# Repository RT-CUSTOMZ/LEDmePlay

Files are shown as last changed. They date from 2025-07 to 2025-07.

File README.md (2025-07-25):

# LEDmeplay-ESP32: Retro Arcade auf dem 32x32 RGB-Matrix-Display

Willkommen zum LEDmeplay-ESP32-Projekt!  

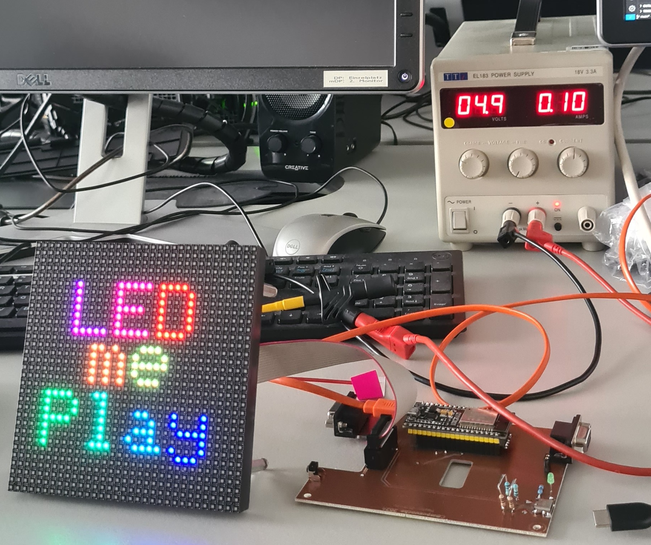
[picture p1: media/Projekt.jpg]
Bild von dem Projekt
 
Dieses Projekt bringt die klassischen LEDmeplay-Spiele von Mithotronic auf ein neues Level: Mit einem leistungsstarken ESP32 als Herzstück lassen sich mehrere Arcade-Spiele auf einem 32x32 Punkte großen RGB-LED-Matrix-Display ausführen und bequem über ein Startmenü auswählen.  
Ziel ist es, ein modulares Open-Source-System zu bieten, das an das Ursprungsprojekt **LEDmeplay für Arduino Mega 2560** anknüpft, aber durch die neue Hardware umfangreicher, moderner und vielseitiger wird.

## Übersicht

- **Plattform:** ESP32
- **Display:** 32x32 RGB-Matrix-LEDs
- **Projekttyp:** PlattformIO-Projekt (Arduino-Shell)
- **Basis:** Erweiterung des Originals von Mithotronic
- **Weitere Inhalte:** FreeCAD-Dateien (Gehäuse-Design als 3D-Druck), KiCad-Schaltpläne (Elektronik), SVG (Laser-Dateien für Gehäuse)

## Hauptfeatures & Verbesserungen

- **Mehrere Spiele:** Dank ESP32 können viele Spiele im Flash gespeichert und via Startmenü ausgewählt werden.
- **Zentrale Spiele-Bibliothek:** Gemeinsame Spiel-Logik und wiederkehrende Routinen wurden als Bibliothek gekapselt – optimale Basis für eigene Spiele-Entwicklungen und unkomplizierte Erweiterbarkeit.
- **Konstante Spielgeschwindigkeit:** Trotz höherer CPU-Geschwindigkeit laufen die klassischen Spiele weiterhin in Original-Geschwindigkeit.
- **Möglichkeit für aufwendigere Spiele:** Der ESP32 eröffnet neue Potenziale für anspruchsvollere Spiele.
- **Gut dokumentierte Beispieldateien:** CAD- und Layout-Daten unterstützen beim Nachbau.

## Bekannte Einschränkungen

- **IO-Pin-Engpass:** Die verfügbaren Pins des ESP32 sind durch Display, Steuerelemente u.a. Geräte fast vollständig belegt.
- **Gestiegene Komplexität:** Das Management mehrerer Spiele sowie die Menüstrukturen erhöhen die Komplexität des Codes. Dies kann das ursprüngliche Ziel, Einsteigerinnen und Einsteigern das Programmieren beizubringen, erschweren.

## Projektstruktur

Das Repository ist logisch gegliedert – jedes Unterverzeichnis enthält klar umrissene Inhalte für die einzelnen Projektaspekte:

| Verzeichnis | Inhalt |
|---|---|
| `/src` | Hauptquellcode für das ESP32-Board, inkl. Spiele, Menü, Bibliotheken |
| `/lib` | Wiederverwendbare Bibliotheken für Spiel-Logik, Displaysteuerung usw. |
| `/data` | Ressourcen wie Fonts, Sprites und Leveldaten |
| `/hardware/` | FreeCAD-Dateien für alle Gehäuseteile (STL für 3D-Druck lassen sich daraus erzeugen) sowie SVG-Dateien, um Gehäuseteile (Frontplatte, Halterungen) mit dem Lasercutter zu fertigen  |
| `/hardware/KiCad/` | KiCad-Projektdateien, Schaltpläne und Boardlayouts für die Elektronik |
| `/docs` | Dokumentation, Tutorials, Installationsanleitungen |

## Installation & Quickstart

1. **Voraussetzungen**
    - ESP32-Board
    - Windows, Mac oder Linux mit [PlatformIO](https://platformio.org/) und Arduino-Core
    - Lötkolben und Basiselektronik-Kenntnisse für Aufbau

2. **Firmware flashen**
    - Repository klonen:
      ```bash
      git clone https://github.com/RT-CUSTOMZ/LEDmePlay.git
      ```
    - PlatformIO-Projekt in VSCode öffnen
    - Board- und Port-Einstellungen anpassen (siehe `platformio.ini`)
    - Kompilieren & Upload:
      ```bash
      pio run --target upload
      ```

3. **Spiele auswählen**
    - Das Startmenü erscheint automatisch nach dem Boot.
    - Spiele lassen sich über angeschlossene Taster auswählen und starten.

## Hardware & Gehäuse

- **3D-Druckteile:**  
  Im Verzeichnis `/hardware/freecad` findest du alle FreeCAD-Dateien (FCStd), mit denen du die Gehäuseteile (z.B. Frontplatten, Halterungen) direkt im 3D-Drucker als STL exportieren kannst.

- **Elektronik und Platinen:**  
  Die Schaltpläne und Board-Layouts sind im Verzeichnis `/hardware/kicad` als KiCad-Projekt (Schaltplandateien, PCB) abgelegt.

- **Laser-Dateien:**  
  Vorlagen für Lasercutter (z.B. Acryl-Front, Tasten-Bohrungen) befinden sich unter `/hardware/`.

## Eigene Spiele entwickeln

- Die gemeinsame Spielelogik steht als Bibliothek unter `/lib` zur Verfügung.
- Beispielprojekte im `/src`-Verzeichnis können dupliziert und angepasst werden.

## Hinweise & Credits

- Dieses Projekt basiert auf dem genialen Ansatz von [Mithotronic LEDmeplay](https://mithotronic.de/ledmeplay.php)
- Bitte respektiere Lizenzen und Quellen beim Weiterverbreiten und Forken.
- Feedback, Fehlerberichte und Spielbeiträge gerne als Pull Request!

**Viel Spaß mit LEDmeplay-ESP32!**

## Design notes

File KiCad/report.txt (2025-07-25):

Hinweis: Verarbeite Symbol "D1:LED_THT:LED_D5.0mm_IRGrey".
Hinweis: Verarbeite Symbol "U1:Espressif:ESP32-DevKitC".
Hinweis: Verarbeite Symbol "SW1:Button_Switch_THT:SW_Tactile_SPST_Angled_PTS645Vx31-2LFS".
Hinweis: Verarbeite Symbol "R3:Resistor_THT:R_Axial_DIN0207_L6.3mm_D2.5mm_P10.16mm_Horizontal".
Hinweis: Verarbeite Symbol "R1:Resistor_THT:R_Axial_DIN0207_L6.3mm_D2.5mm_P10.16mm_Horizontal".
Hinweis: Verarbeite Symbol "Q1:Package_TO_SOT_THT:TO-92L".
Hinweis: Verarbeite Symbol "J6:Connector_Phoenix_MSTB:PhoenixContact_MSTBA_2,5_4-G-5,08_1x04_P5.08mm_Horizontal".
Hinweis: Verarbeite Symbol "J4:Connector_Dsub:DSUB-9_Female_Horizontal_P2.77x2.84mm_EdgePinOffset4.94mm_Housed_MountingHolesOffset7.48mm".
Hinweis: Verarbeite Symbol "J3:Connector_Dsub:DSUB-9_Female_Horizontal_P2.77x2.84mm_EdgePinOffset4.94mm_Housed_MountingHolesOffset7.48mm".
Hinweis: Verarbeite Symbol "J2:Connector_IDC:IDC-Header_2x08_P2.54mm_Vertical".
Hinweis: Verarbeite Symbol "H4:MountingHole:MountingHole_3.5mm".
Hinweis: Verarbeite Symbol "BZ1:Buzzer_Beeper:MagneticBuzzer_PUI_AT-0927-TT-6-R".
Hinweis: Verarbeite Symbol "D2:Diode_THT:D_A-405_P12.70mm_Horizontal".
Hinweis: Verarbeite Symbol "FID1:Fiducial:Fiducial_1.5mm_Mask3mm".
Hinweis: Verarbeite Symbol "FID2:Fiducial:Fiducial_1.5mm_Mask3mm".
Hinweis: Verarbeite Symbol "FID3:Fiducial:Fiducial_1.5mm_Mask3mm".
Hinweis: Verarbeite Symbol "H1:MountingHole:MountingHole_3.5mm_Pad_TopBottom".
Hinweis: Verarbeite Symbol "H2:MountingHole:MountingHole_3.5mm".
Hinweis: Verarbeite Symbol "H3:MountingHole:MountingHole_3.5mm".
Hinweis: Verarbeite Symbol "J1:Connector_BarrelJack:BarrelJack_Wuerth_6941xx301002".
Wert J6 von Conn_01x04_Socket in +5V-Display geändert.
J6 Pin 2 von +5V nach GND wieder verbunden.
J6 Pin 3 von GND nach +5V wieder verbunden.
J6 Pin 1 von +5V nach GND wieder verbunden.
J6 Pin 4 von GND nach +5V wieder verbunden.
Warnung: Kein Netz für Komponente J4 Pad 0 gefunden (kein Pin 0 in Symbol).
Warnung: Kein Netz für Komponente J4 Pad 0 gefunden (kein Pin 0 in Symbol).
Warnung: Kein Netz für Komponente J3 Pad 0 gefunden (kein Pin 0 in Symbol).
Warnung: Kein Netz für Komponente J3 Pad 0 gefunden (kein Pin 0 in Symbol).

Hinweis: Warnungen insgesamt: 4, Fehler insgesamt: 0.

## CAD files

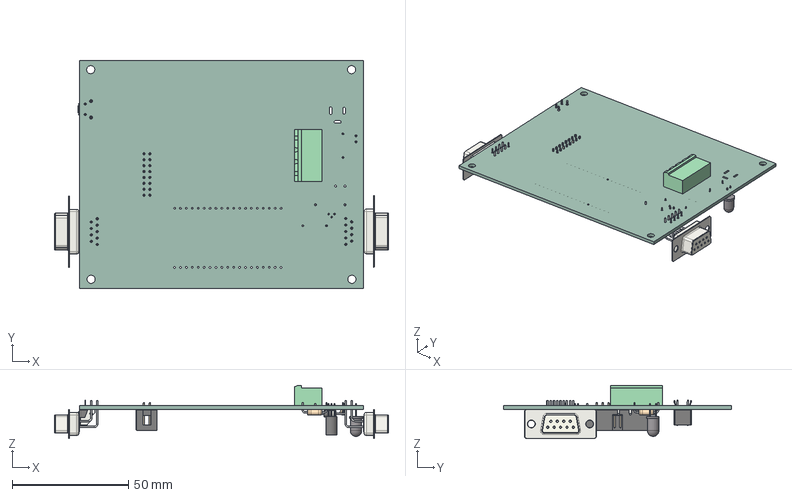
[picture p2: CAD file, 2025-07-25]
KiCad/Display-PLAY-Me_2.step
143.4 x 98.0 x 22.8 mm
MSTBA_01x04_G_5_08mm
SW_Tactile_SPST_Angled_PTS645Vx31-2LFS
D_A-405_P12.70mm_Horizontal
LED_D5.0mm_IRGrey
TO-92L_Narrow
DSUB-9_Female_Horizontal_P2.77x2.54mm_EdgePinOffset9.40mm x 2
R_Axial_DIN0207_L63mm_D25mm_P1016mm_Horizontal x 2
IDC_Header_2x08_P254mm_Vertical
Display-PLAY-Me_2_PCB

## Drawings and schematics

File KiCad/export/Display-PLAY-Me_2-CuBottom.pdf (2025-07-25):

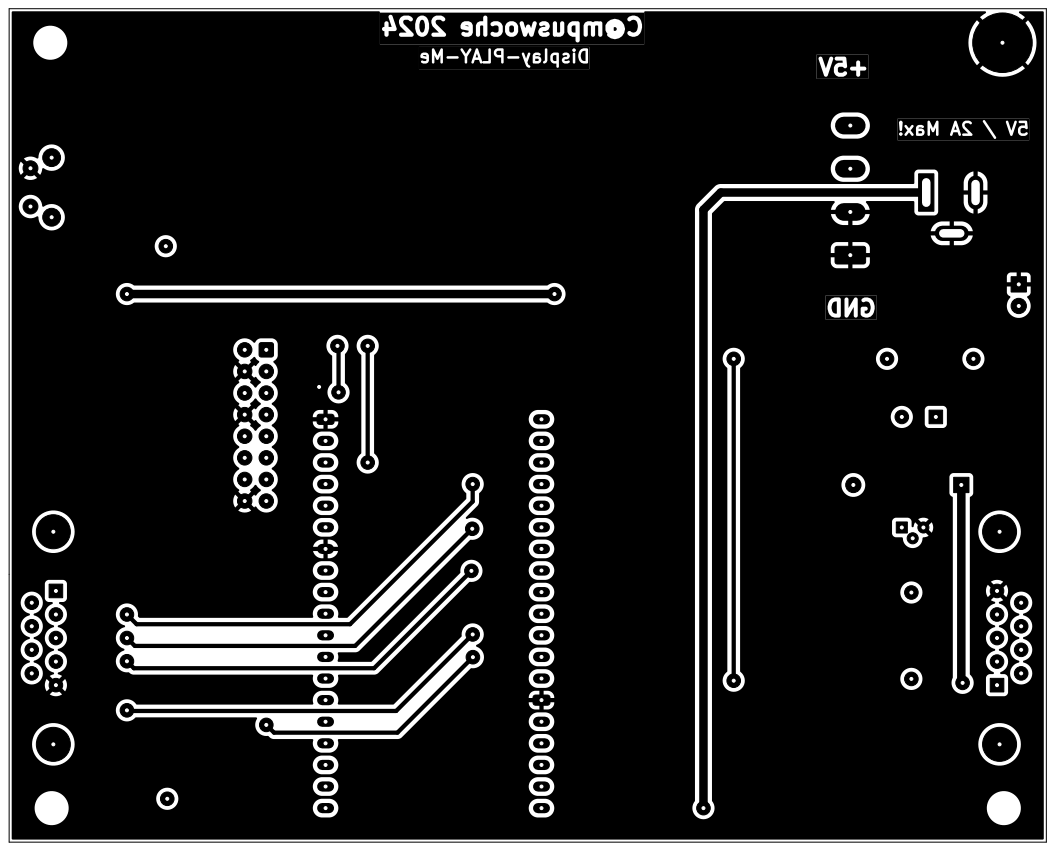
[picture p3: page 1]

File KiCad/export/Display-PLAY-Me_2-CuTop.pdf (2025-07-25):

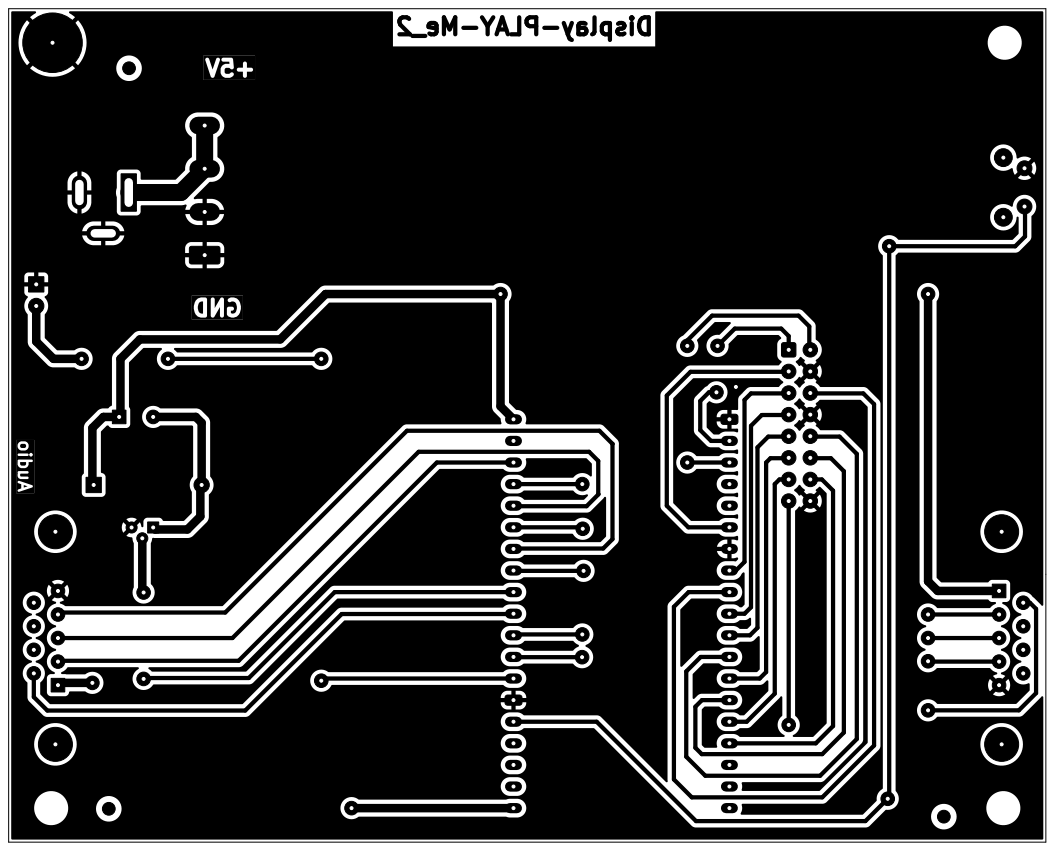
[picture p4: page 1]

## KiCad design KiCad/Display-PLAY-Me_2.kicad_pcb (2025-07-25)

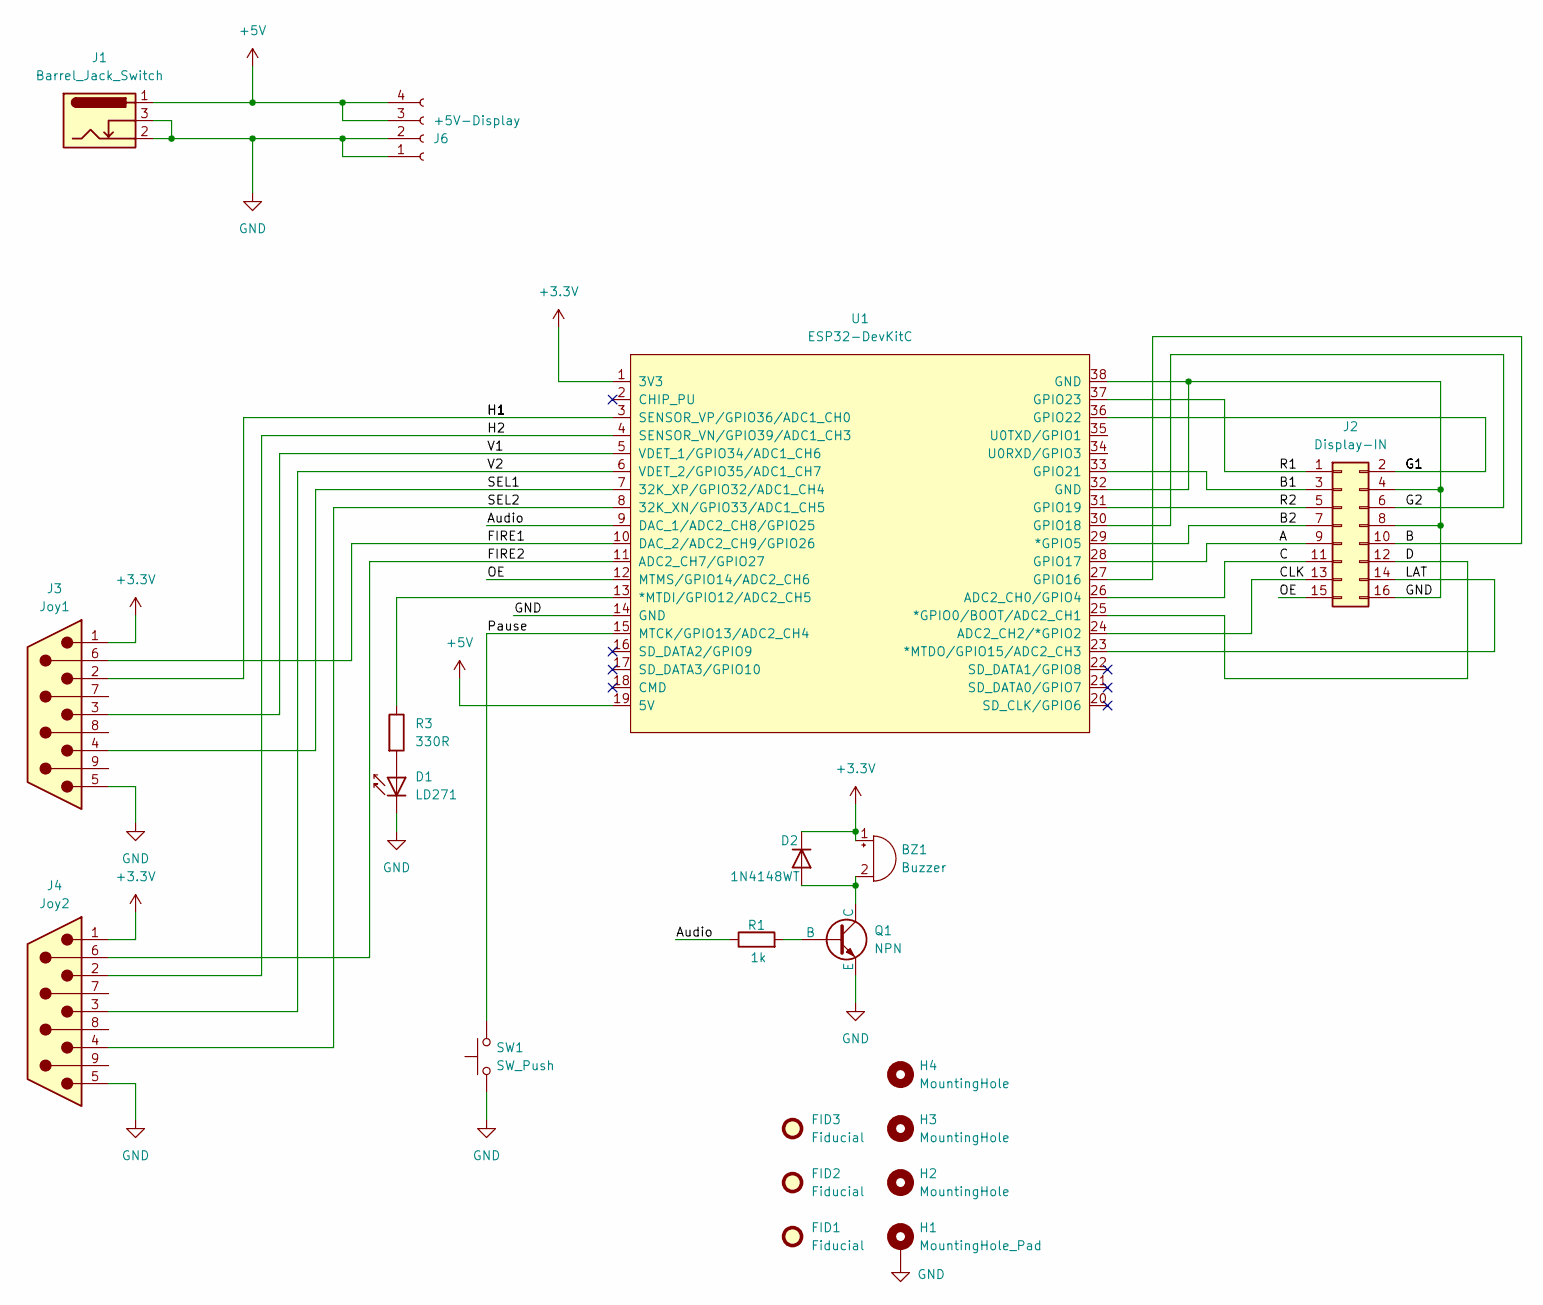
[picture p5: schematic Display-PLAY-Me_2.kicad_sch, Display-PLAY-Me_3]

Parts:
BZ1: Buzzer; MagneticBuzzer_PUI_AT-0927-TT-6-R
D1: LD271; LED_D5.0mm_IRGrey
D2: 1N4148WT; D_A-405_P12.70mm_Horizontal
FID1, FID2, FID3: Fiducial; Fiducial_1.5mm_Mask3mm
H1: MountingHole_Pad; MountingHole_3.5mm_Pad_TopBottom
H2, H3, H4: MountingHole; MountingHole_3.5mm
J1: Barrel_Jack_Switch; BarrelJack_Wuerth_6941xx301002
J2: Display-IN; IDC-Header_2x08_P2.54mm_Vertical
J3: Joy1; DSUB-9_Female_Horizontal_P2.77x2.84mm_EdgePinOffset4.94mm_H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
J4: Joy2; DSUB-9_Female_Horizontal_P2.77x2.84mm_EdgePinOffset4.94mm_H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
J6: +5V-Display; PhoenixContact_MSTBA_2,5_4-G-5,08_1x04_P5.08mm_Horizontal
Q1: NPN; TO-92L
R1: 1k; R_Axial_DIN0207_L6.3mm_D2.5mm_P10.16mm_Horizontal
R3: 330R; R_Axial_DIN0207_L6.3mm_D2.5mm_P10.16mm_Horizontal
SW1: SW_Push; SW_Tactile_SPST_Angled_PTS645Vx31-2LFS
U1: ESP32-DevKitC

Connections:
+3.3V: BZ1.1 (+), D2.1 (K), J3.1, J4.1, U1.1 (3V3)
+5V: J1.1, J6.3, J6.4, U1.19 (5V)
/A: J2.9, U1.28 (GPIO17)
/Audio: R1.1, U1.9 (DAC_1/ADC2_CH8/GPIO25)
/B: J2.10, U1.27 (GPIO16)
/B1: J2.3, U1.33 (GPIO21)
/B2: J2.7, U1.29 (*GPIO5)
/C: J2.11, U1.26 (ADC2_CH0/GPIO4)
/CLK: J2.13, U1.24 (ADC2_CH2/*GPIO2)
/D: J2.12, U1.25 (*GPIO0/BOOT/ADC2_CH1)
/FIRE1: J3.6, U1.10 (DAC_2/ADC2_CH9/GPIO26)
/FIRE2: J4.6, U1.11 (ADC2_CH7/GPIO27)
/G2: J2.6, U1.30 (GPIO18)
/H2: J4.2, U1.4 (SENSOR_VN/GPIO39/ADC1_CH3)
/LAT: J2.14, U1.23 (*MTDO/GPIO15/ADC2_CH3)
/OE: J2.15, U1.12 (MTMS/GPIO14/ADC2_CH6)
/Pause: SW1.2, U1.15 (MTCK/GPIO13/ADC2_CH4)
/R1: J2.1, U1.37 (GPIO23)
/R2: J2.5, U1.31 (GPIO19)
/SEL1: J3.4, U1.7 (32K_XP/GPIO32/ADC1_CH4)
/SEL2: J4.4, U1.8 (32K_XN/GPIO33/ADC1_CH5)
/V1: J3.3, U1.5 (VDET_1/GPIO34/ADC1_CH6)
/V2: J4.3, U1.6 (VDET_2/GPIO35/ADC1_CH7)
GND: D1.1 (K), H1.1, J1.2, J1.3, J2.4, J2.8, J2.16, J3.5, J4.5, J6.1, J6.2, Q1.3 (E), SW1.1, U1.14 (GND), U1.32 (GND), U1.38 (GND)
unnamed: BZ1.2 (-), D2.2 (A), Q1.1 (C)
unnamed: D1.2 (A), R3.2
unnamed: J2.2, U1.36 (GPIO22)
unnamed: Q1.2 (B), R1.2
unnamed: R3.1, U1.13 (*MTDI/GPIO12/ADC2_CH5)
unnamed: J3.2, U1.3 (SENSOR_VP/GPIO36/ADC1_CH0)

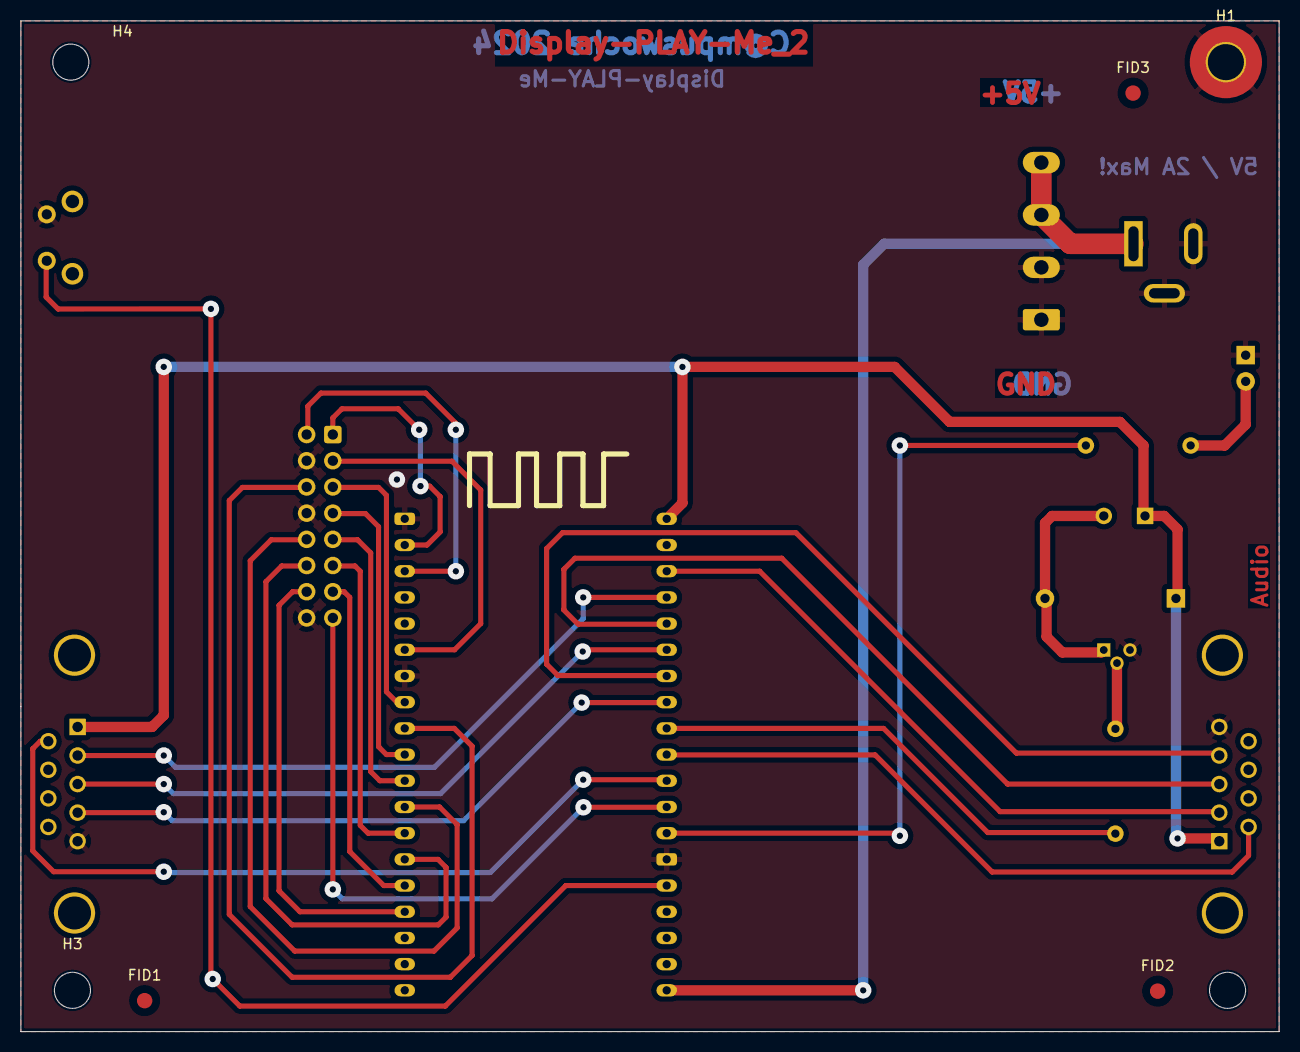
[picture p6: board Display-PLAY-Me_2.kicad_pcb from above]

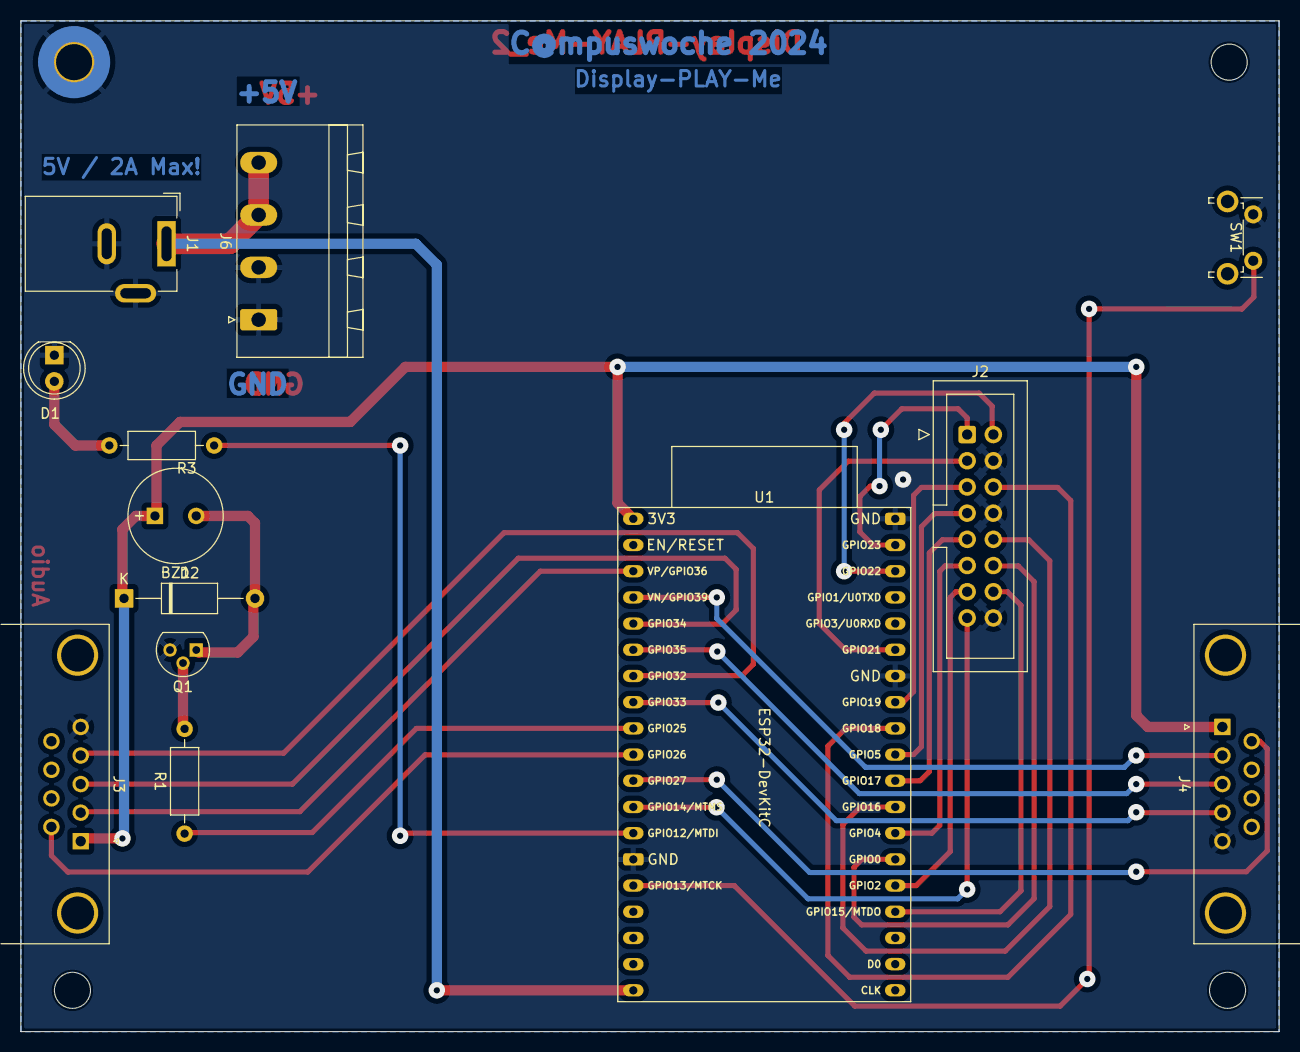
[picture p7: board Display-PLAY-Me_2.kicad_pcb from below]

Board: 2 copper layers, 122.0 x 98.0 mm, 20 parts (13 on the bottom side), 30 nets.

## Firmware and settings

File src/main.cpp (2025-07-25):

#include <hardware_setup.hpp>

void setup_Invaders();
void loop_Invaders();

void setup_Gigapede();
void loop_Gigapede();

void setup_joy();
void loop_joy();

void setup_Pacer();
void loop_Pacer();

uint8_t selectGame();

struct GameMethods myGames[] = {
    {"Invaders", &setup_Invaders, &loop_Invaders},
    {"Gentipede", &setup_Gigapede, &loop_Gigapede},
    {"Pacer", &setup_Pacer, &loop_Pacer},
    {"TestJoy", &setup_joy, &loop_joy},
    {"Carambolage", &setup_Invaders, &loop_Invaders},
    {"Lara Croft", &setup_Gigapede, &loop_Gigapede},
    {"Dortmund", &setup_joy, &loop_joy},
    {"Ende", NULL}};

u_int8_t ldm_game = 3;

void setup()
{
    hardware_init();
    ldm_game = selectGame();
    // Serial.println(ldm_game);
    // ldm_game=2;
    myGames[ldm_game].setup();
}

void loop()
{
    myGames[ldm_game].loop();
}

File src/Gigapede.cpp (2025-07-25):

// Gigapede
// for the LEDmePlay
//
// www.mithotronic.de
//
// Version: 1.1.1
// Author: Michael Rosskopf (2013)
//
// Many thanks Thomas Laubach!
//
// Release Notes:
// V1.1.1: Support of LEDmePI (2021)
// V1.1.0: Support of LEDmePlay Joypad and LEDmePlayBoy (2018)
// V1.0.1: Smaller improvements (colors adapted for IDE 1.x, waiting in status screens can be skipped with fire button)
// V1.0.0: First release

#include <hardware_setup.hpp> // Initialization of hardware definitions
#include <Notes.hpp>    // Initialization of music note definitions
#include <LmP_base.hpp>

// Playfield
byte playfield_gigapede[32][32]; // 0 == empty, 1 == centipede, 2 == mushroom, 3 == shot, 4 == spider, 5 == bug, 6 == dragonfly

// Enemies

// Centipede
byte lengthOfCentipede = 16;
byte centipedeX[24];
byte centipedeY[24];
byte centipedeDirection[24]; // 0 == killed, 1 == right down, 2 == left down, 3 == right up, 4 == left up
byte segmentsKilled;
boolean centipedeKilled;

// Spider
int spiderX;
int spiderY;
byte spiderDirection; // 0 == absent, 1 == right down, 2 == left down, 3 == right up, 4 == left up

// Bug
int bugX;
int bugY;
boolean bugPresent;

// Dragonfly (first appears in level 3)
int dragonflyX;
int dragonflyY;
byte dragonflyDirection; // 0 == absent, 1 == right down, 2 == left down

// Guns and shots
byte numberOfPlayers;
byte gunX[2];
byte gunY[2];
byte shotX[2];
byte shotY[2];
boolean shotFired[2];

// Level settings
byte level_gigapede;
byte lives_gigapede[2];
int score_gigapede[2];
int extraLifeScore_gigapede[2];
int highScore_gigapede = 0;
int gameSpeed;
int enemyProbability;
boolean reset; // if true, return to title screen

// Colors
byte gun1R;
byte gun1G;
byte gun1B;
byte gun2R;
byte gun2G;
byte gun2B;
byte centipedeR;
byte centipedeG;
byte centipedeB;
byte mushroomR;
byte mushroomG;
byte mushroomB;
byte spiderR;
byte spiderG;
byte spiderB;
byte bugR;
byte bugG;
byte bugB;
byte colors[6];
byte newColor;
boolean newColorFound;

// Function declarations
void setupGame_gigapede();
void setupLevel_gigapede();
void setColor(byte color, byte &color_R, byte &color_G, byte &color_B);
void moveCentipede();
void moveSpider();
void moveBug();
void moveDragonfly();
void moveGun();
void moveShot_gigapede();
void drawMushrooms(int _numberOfMushrooms);
boolean collisionDetection();
void explosion_gigapede(byte _x, byte _y);
void wait(int _waitingTime);

void setup_Gigapede()
{
  hardware_init();

  // Mithotronic logo
  mithotronic();
  ledMePlay();
}

// Start screen and game options selection (difficulty and number of players)
void setupGame_gigapede()
{
  // Reset set to false
  reset = false;

  // Title screen
  matrix.fillScreen(matrix.Color333(0, 0, 0));
  matrix.setCursor(4, 0);
  matrix.setTextColor(matrix.Color333(0, 5, 0));
  matrix.println("Giga");
  matrix.setCursor(4, 8);
  matrix.setTextColor(matrix.Color333(0, 5, 0));
  matrix.println("pede");
  matrix.setCursor(1, 16);
  matrix.setTextColor(matrix.Color333(3, 3, 0));
  matrix.println("HiScr");
  matrix.setCursor(1, 24);
  matrix.println(highScore_gigapede);

  // Initialize level score etc.
  score_gigapede[0] = 0;
  score_gigapede[1] = 0;
  lives_gigapede[0] = 3;
  lives_gigapede[1] = 3;
  extraLifeScore_gigapede[0] = 0;
  extraLifeScore_gigapede[1] = 0;
  level_gigapede = 1;

  // Jingle on start screen
  tone(audioPacer, 523, 200);
  delay(200);
  tone(audioPacer, 659, 200);
  delay(200);
  tone(audioPacer, 784, 200);
  delay(200);
  tone(audioPacer, 1047, 400);
  delay(400);
  tone(audioPacer, 784, 200);
  delay(200);
  tone(audioPacer, 1047, 400);
  delay(400);

  // Wait until player 1 presses fire
  do
  {
  } while (!joy1Fire());
  tone(audioPacer, 1024, 20);
  delay(200);

  // Select difficulty (defined by length of centipede)
  matrix.fillRect(0, 16, 32, 16, matrix.Color333(0, 0, 0));
  matrix.setCursor(1, 16);
  matrix.setTextColor(matrix.Color333(3, 3, 0));
  matrix.println("Diff");
  matrix.setCursor(1, 24);
  delay(200);

  do
  {
    if (joy1Left())
    {
      if (lengthOfCentipede > 12)
      {
        lengthOfCentipede = lengthOfCentipede - 4;
        matrix.fillRect(0, 24, 32, 8, matrix.Color333(0, 0, 0));
        tone(audioPacer, 1024, 20);
        delay(200);
      }
    }
    if (joy1Right())
    {
      if (lengthOfCentipede < 24)
      {
        lengthOfCentipede = lengthOfCentipede + 4;
        matrix.fillRect(0, 24, 32, 8, matrix.Color333(0, 0, 0));
        tone(audioPacer, 1024, 20);
        delay(200);
      }
    }
    matrix.setCursor(1, 24);
    switch (lengthOfCentipede)
    {
    case 12:
      matrix.println("Light");
      break;

    case 16:
      matrix.println("Med");
      break;

    case 20:
      matrix.println("Hard");
      break;

    case 24:
      matrix.println("Ultra");
      break;
    }
  } while (!joy1Fire());
  tone(audioPacer, 1024, 20);
  delay(200);

  // Select number of players
  matrix.fillRect(0, 16, 32, 16, matrix.Color333(0, 0, 0));
  matrix.setCursor(1, 16);
  matrix.setTextColor(matrix.Color333(3, 3, 0));
  matrix.println("Plyrs");
  matrix.setCursor(1, 24);
  numberOfPlayers = 1;

  do
  {
    if (joy1Left() && numberOfPlayers != 1)
    {
      numberOfPlayers = 1;
      matrix.fillRect(0, 24, 32, 8, matrix.Color333(0, 0, 0));
      tone(audioPacer, 1024, 20);
      delay(200);
    }
    if (joy1Right() && numberOfPlayers != 2)
    {
      numberOfPlayers = 2;
      matrix.fillRect(0, 24, 32, 8, matrix.Color333(0, 0, 0));
      tone(audioPacer, 1024, 20);
      delay(200);
    }
    matrix.setCursor(14, 24);
    matrix.println(numberOfPlayers);
  } while (!joy1Fire());
  tone(audioPacer, 1024, 20);
  delay(200);
}
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
